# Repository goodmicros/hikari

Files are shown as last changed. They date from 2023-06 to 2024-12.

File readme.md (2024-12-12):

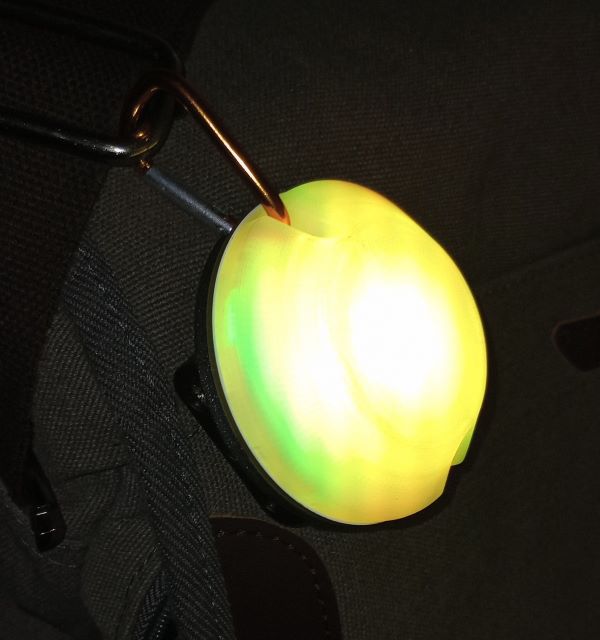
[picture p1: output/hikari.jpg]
badge


# Hikari
This is an all-in-one, battery powered, single RGBW led module designed to be used with the [WLED project](https://wled.me).
The goal is to provide inexpensive, portable lights for events and DIY use.

## Usage
Connect 3x AAA batteries and switch on. The USB port can be used to bypass the battery pack for extended usage.

If you want, you can further configure / adjust the light color and effects over WLAN with:
* WLED native phone app: [iOS App Store](https://apps.apple.com/us/app/wled-native/id6446207239) - [Google Play](https://play.google.com/store/apps/details?id=ca.cgagnier.wlednativeandroid)
* [LedFX](https://www.ledfx.app/) 
* [WLED compatibles](https://github.com/Aircoookie/WLED#-supported-light-control-interfaces)
* or by connecting to the device's IP address

### Modes  
* The switch turns the whole module on/off
* The button puts the device into sleep
* Two button presses sets the color to white (and disables the live mode)
    * back to normal with a long press
    * reboot the device to enable live mode again
* Hold the button for 6 seconds to reset WLAN config
* Hold the button for more than 12 seconds to factory reset WLED settings

## Wireless control / WLAN fallback
By default the device is looking for a Good Micros WLAN and tries to connect to it. 
If it can't find the WLAN it will create an access point which you can connect with your phone or laptop to change the effects and settings.  
The AP name is hikari- + the number of your device which is also printed on a sticker in the battery case. The default password for the AP is wled1234.

## Design requirements
* WLED compatible
* Battery powered with the possibility to bypass with USB power
* Brightness comparable to a strip of ws2812b leds
* Programmable without external hardware

## Troubleshooting
|issue|cause|solution|
|-----|-----|---|
|only green works| low battery| replace batteries or connect USB|
|stuck on red| USB connected while powered off| disconnect USB -> switch on -> connect USB|
|stuck on red| button pressed while powering on| power off -> power on without pressing button|

## Configuration (Advanced usage)
Install WLED via https://install.wled.me/  

The switch should be in the power-on position when programming.
If WLED installer doesn't allow you to erase the memory, hold the switch while connecting the power (the light should stay red).  

After successful flashing remove the device and plug it back in to refresh the serial port. After connecting you have the option to connect the device to WLAN. If it doesn't appear instantly press one of the options from WLED installer and click back to refresh the view.

pin configuration on WLED:
|color|pin|
|-----|---|
| red |16 |
|green|14 |
|blue |12 |
|white|13 |

[Case model](https://cad.onshape.com/documents/9da918a63413a7b839d4e473/w/a43791fa43f813add74c9832/e/dfbc73c4b037cd1ff73a47b7)

## Bugs
* ~CH340G VCC should be connected to 3.3V~

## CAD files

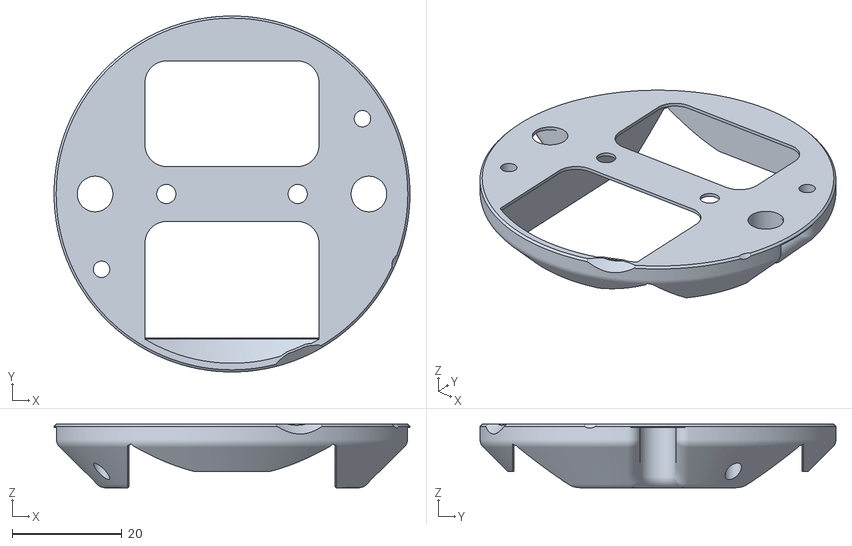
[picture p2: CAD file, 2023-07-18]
output/hikari_bottom_final.stl
65.0 x 65.0 x 11.6

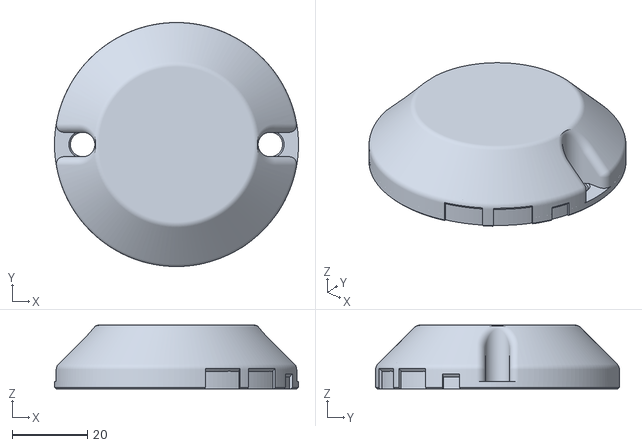
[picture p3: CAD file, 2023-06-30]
output/hikari_diffuser_final.stl
65.0 x 65.0 x 17.0

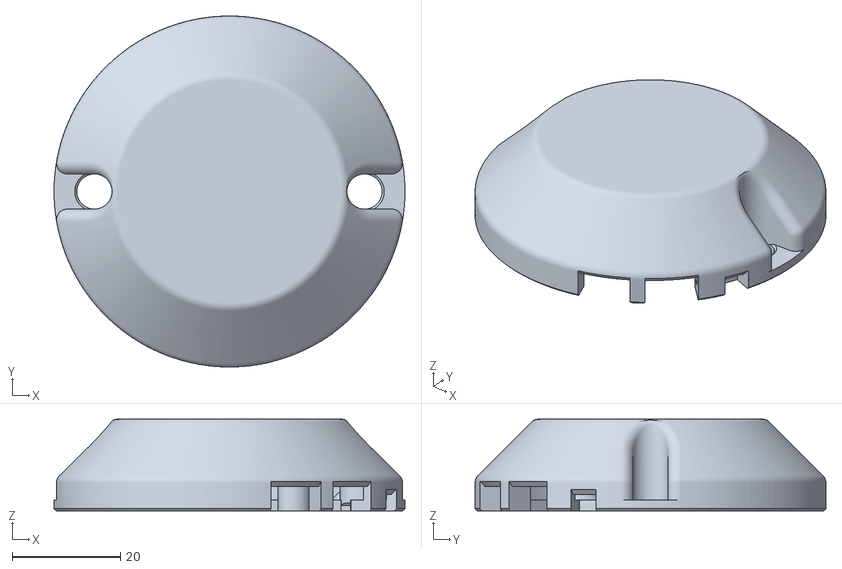
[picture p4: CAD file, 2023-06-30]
output/hikari_diffuser_final_no_supports.stl
65.0 x 65.0 x 17.0

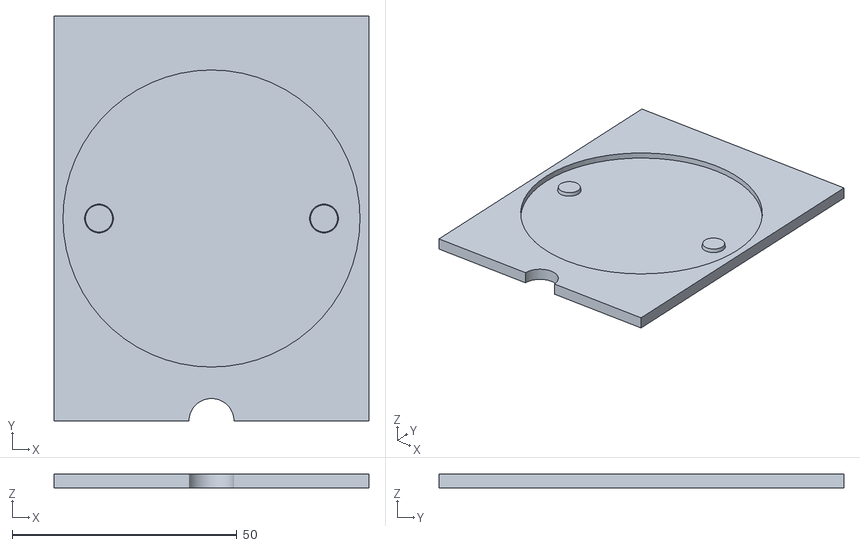
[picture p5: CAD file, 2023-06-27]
output/stencil-holder.stl
70.0 x 90.0 x 3.20

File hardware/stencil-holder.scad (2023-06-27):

$fn=60;
difference(){
    cube([70,90,2*1.6],center=true);
    cylinder(d=66, height = 1,6);
    translate([0,-45,0])
        cylinder(d=10,h=4, center=true);
}
for(a = [0,180]){
    rotate([0,0,a])
        translate([50/2,0,0])
            cylinder(d1=6.4, d2=6,  height = 1);
}

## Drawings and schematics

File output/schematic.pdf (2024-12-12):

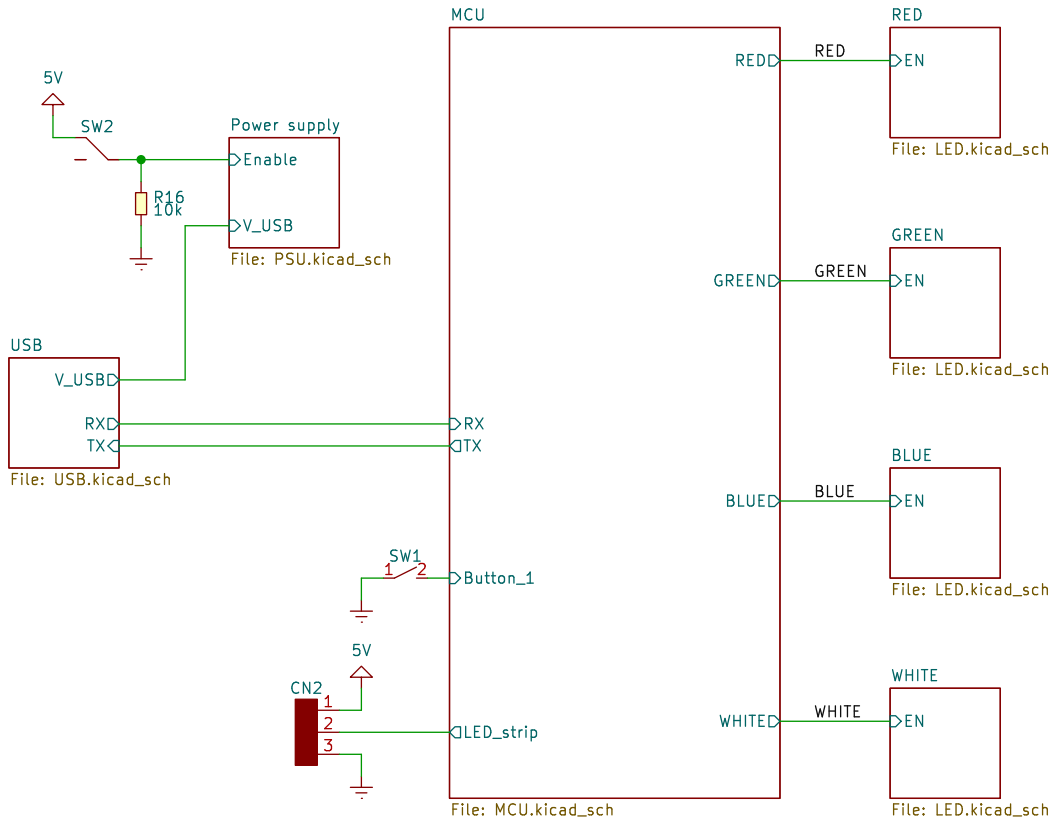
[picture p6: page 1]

File: LED.kicad_sch WHITE GREEN

Id: 1/8 Title: File: hikari.kicad_sch Sheet: /

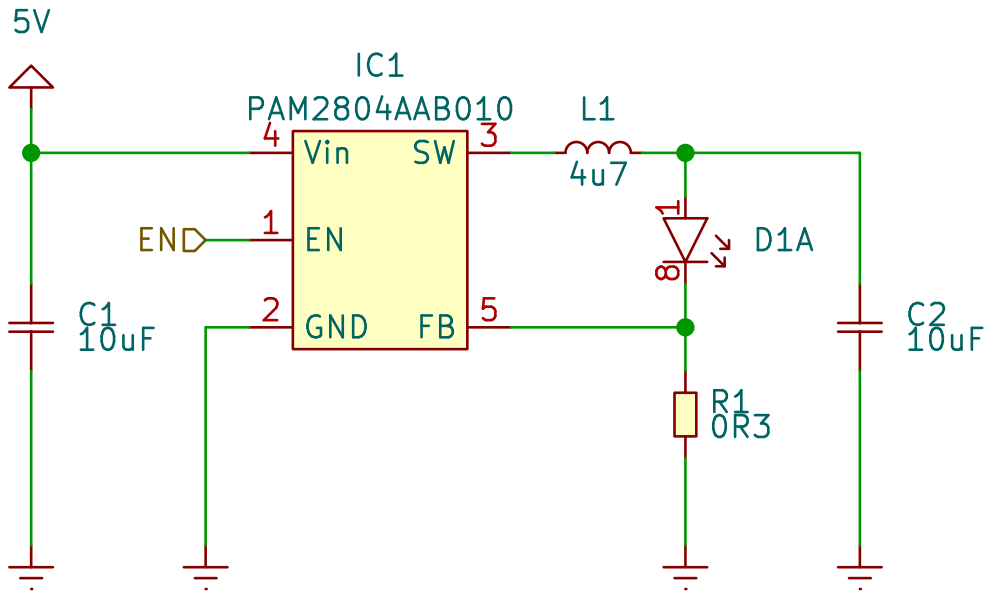
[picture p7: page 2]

Id: 2/8 Title: File: LED.kicad_sch Sheet: /RED/ C2

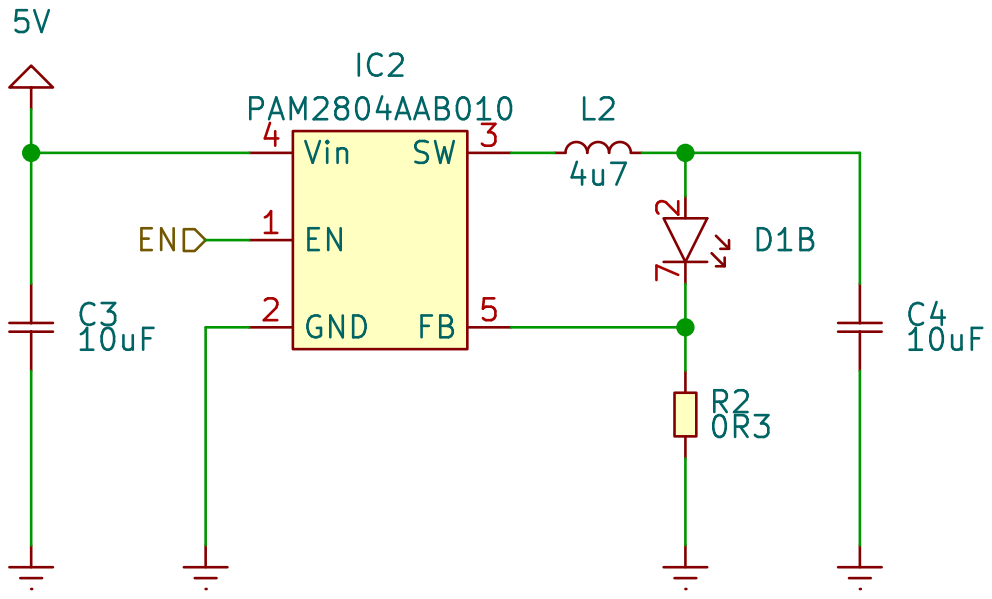
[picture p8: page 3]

Id: 3/8 Title: File: LED.kicad_sch Sheet: /GREEN/ C4

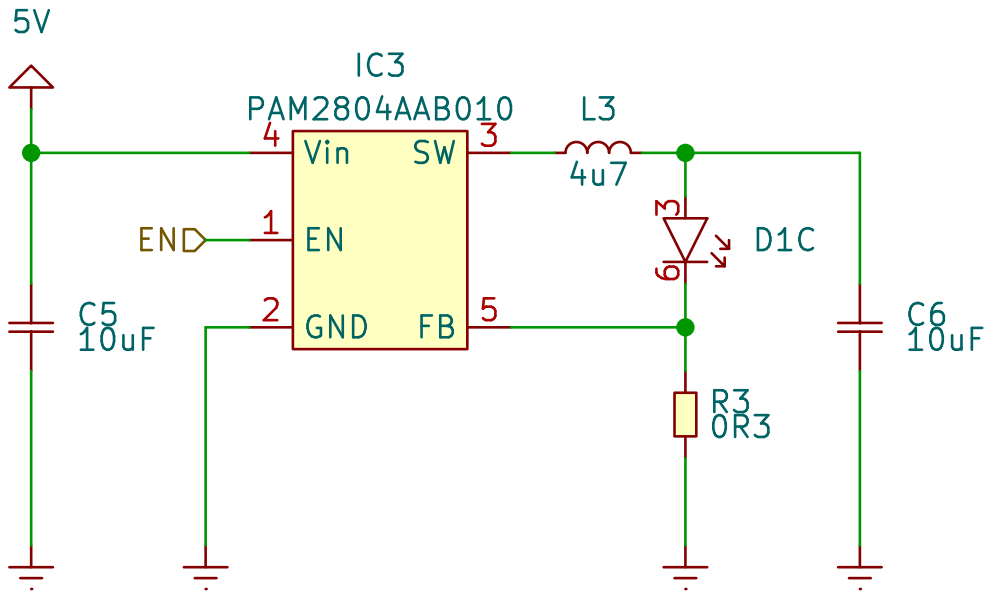
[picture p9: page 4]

Id: 4/8 Title: File: LED.kicad_sch Sheet: /BLUE/ C6

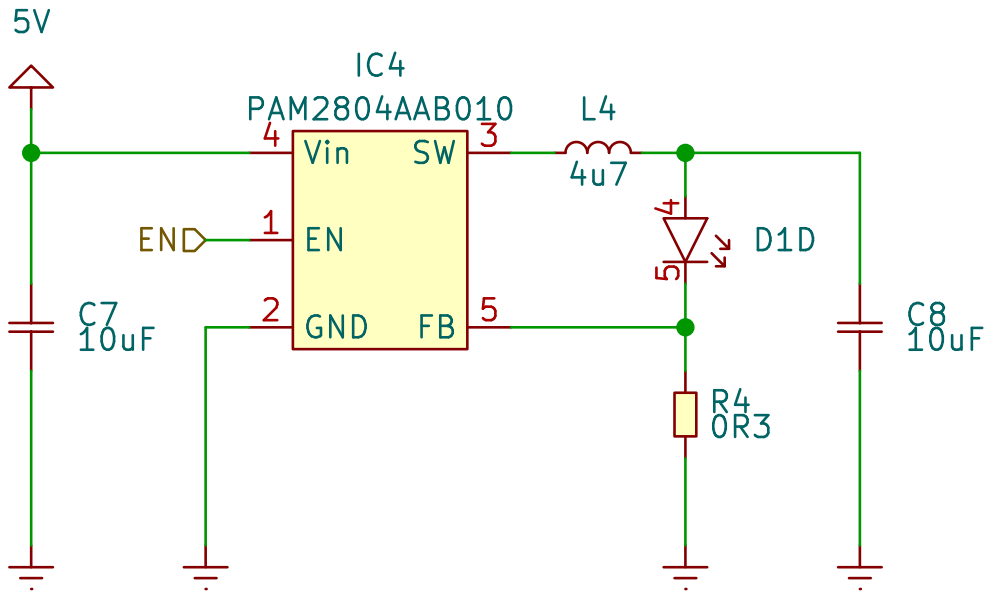
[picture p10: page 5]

Id: 5/8 Title: File: LED.kicad_sch Sheet: /WHITE/ C8

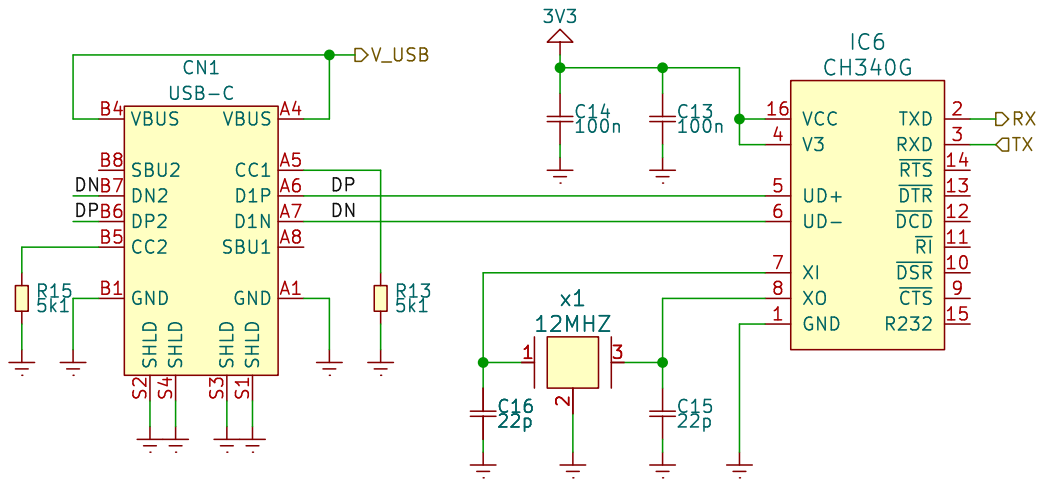
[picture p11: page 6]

Id: 6/8 Title: File: USB.kicad_sch Sheet: /USB/

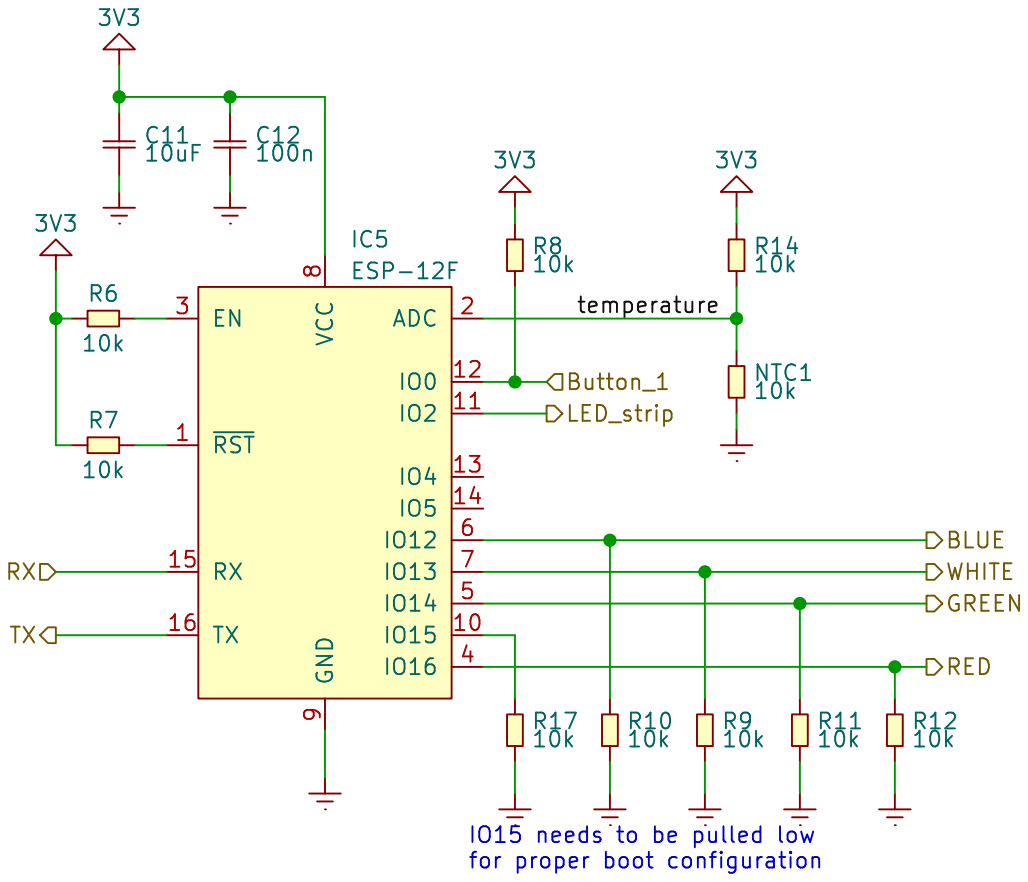
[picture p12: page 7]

Id: 7/8 Title: File: MCU.kicad_sch Sheet: /MCU/ R9

IO15 needs to be pulled low
for proper boot configuration

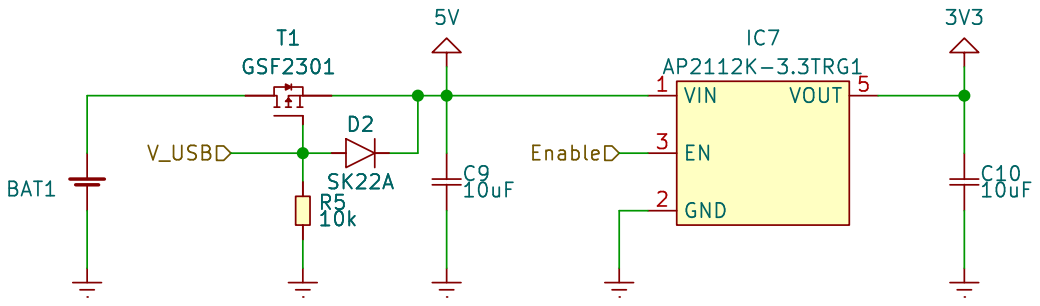
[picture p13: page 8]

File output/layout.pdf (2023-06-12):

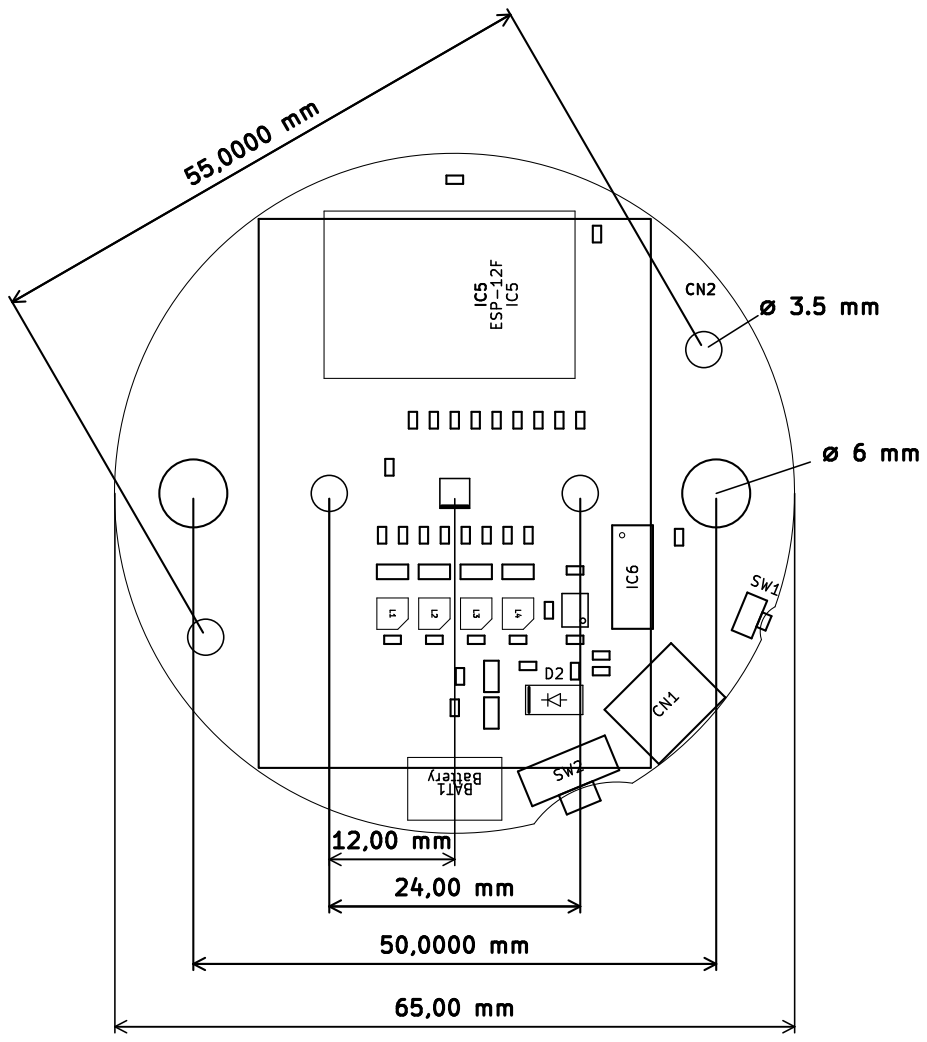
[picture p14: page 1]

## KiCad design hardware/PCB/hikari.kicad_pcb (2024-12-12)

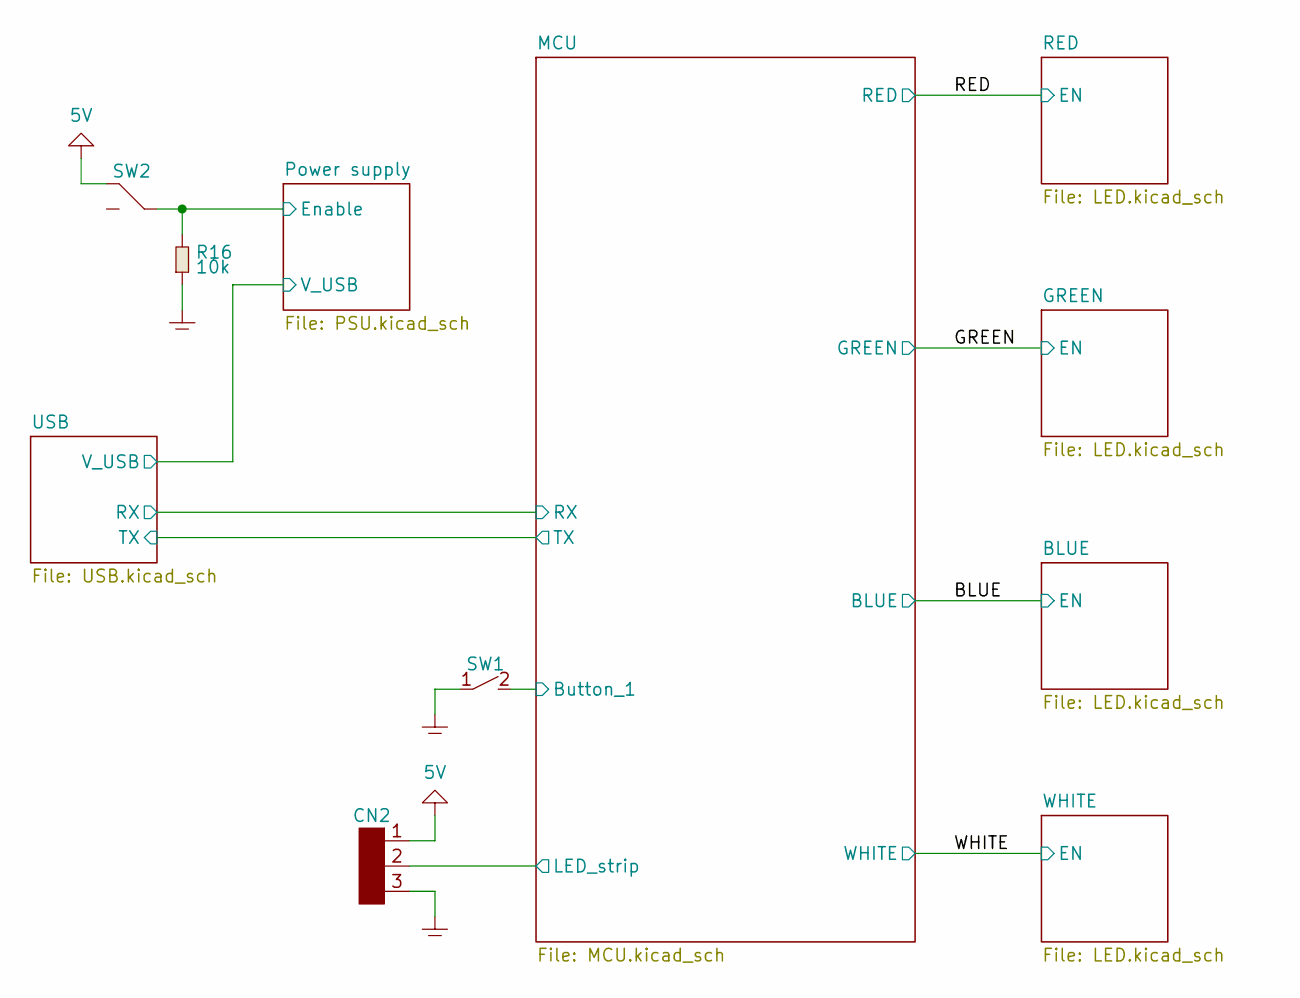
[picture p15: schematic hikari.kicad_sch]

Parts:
CN2: 1x3
R16: 10k; 0603; Digi-Key 13-RC0603JR-1010KLCT-ND
SW1: LS12W3-T; Digi-Key 1642-LS12W3-TCT-ND
SW2: JS102011SAQN; Digi-Key 401-1999-1-ND

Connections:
5V: CN2.1, SW2.1; also elsewhere on the board
/MCU/Button_1: SW1.2; also elsewhere on the board
/MCU/LED_strip: CN2.2; also elsewhere on the board
/Power supply/Enable: R16.2, SW2.2; also elsewhere on the board
GND: CN2.3, R16.1, SW1.0, SW1.1; also elsewhere on the board
unnamed: SW2.3, SW2.4

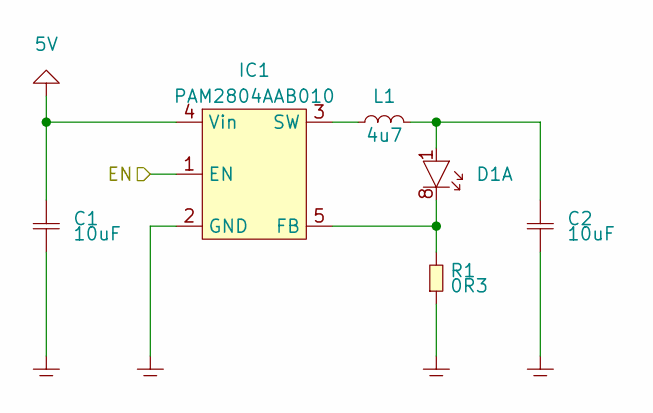
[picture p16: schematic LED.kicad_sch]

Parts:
C1, C2: 10uF; 0603; Digi-Key 1276-1119-1-ND
D1: QLSP06RGBXWAJ; 3030_8; MPN QLSP06RGBXWAJ; Digi-Key 3970-QLSP06RGBXWAJCT-ND
IC1: PAM2804AAB010; SOT-23-5; MPN PAM2804AAB010; Digi-Key PAM2804AAB010DICT-ND
L1: 4u7; CDRH2D11; Digi-Key 308-1590-1-ND
R1: 0R3; 0603; Digi-Key 273-KDV06FR300ETCT-ND

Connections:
5V: C1.1, IC1.4 (Vin); also elsewhere on the board
/RED: IC1.1 (EN); also elsewhere on the board
GND: C1.2, C2.2, IC1.2 (GND), R1.1; also elsewhere on the board
unnamed: C2.1, D1.1 (A), L1.2
unnamed: D1.8 (K), IC1.5 (FB), R1.2
unnamed 21: D1.2 (A); also elsewhere on the board
unnamed 22: D1.7 (K); also elsewhere on the board
unnamed 23: D1.3 (A); also elsewhere on the board
unnamed 24: D1.6 (K); also elsewhere on the board
unnamed 25: D1.4 (A); also elsewhere on the board
unnamed 26: D1.5 (K); also elsewhere on the board
unnamed: IC1.3 (SW), L1.1

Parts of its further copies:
C3, C4, C5, C6, C7, C8: 10uF; 0603; Digi-Key 1276-1119-1-ND
IC2, IC3, IC4: PAM2804AAB010; SOT-23-5; MPN PAM2804AAB010; Digi-Key PAM2804AAB010DICT-ND
L2, L3, L4: 4u7; CDRH2D11; Digi-Key 308-1590-1-ND
R2, R3, R4: 0R3; 0603; Digi-Key 273-KDV06FR300ETCT-ND

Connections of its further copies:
5V: C3.1, C5.1, C7.1, IC2.4 (Vin), IC3.4 (Vin), IC4.4 (Vin); also elsewhere on the board
/BLUE: IC3.1 (EN); also elsewhere on the board
/GREEN: IC2.1 (EN); also elsewhere on the board
/WHITE: IC4.1 (EN); also elsewhere on the board
GND: C3.2, C4.2, C5.2, C6.2, C7.2, C8.2, IC2.2 (GND), IC3.2 (GND), IC4.2 (GND), R2.1, R3.1, R4.1; also elsewhere on the board
unnamed 21: C4.1, L2.2; also elsewhere on the board
unnamed 22: IC2.5 (FB), R2.2; also elsewhere on the board
unnamed 23: C6.1, L3.2; also elsewhere on the board
unnamed 24: IC3.5 (FB), R3.2; also elsewhere on the board
unnamed 25: C8.1, L4.2; also elsewhere on the board
unnamed 26: IC4.5 (FB), R4.2; also elsewhere on the board
unnamed: IC2.3 (SW), L2.1
unnamed: IC3.3 (SW), L3.1
unnamed: IC4.3 (SW), L4.1

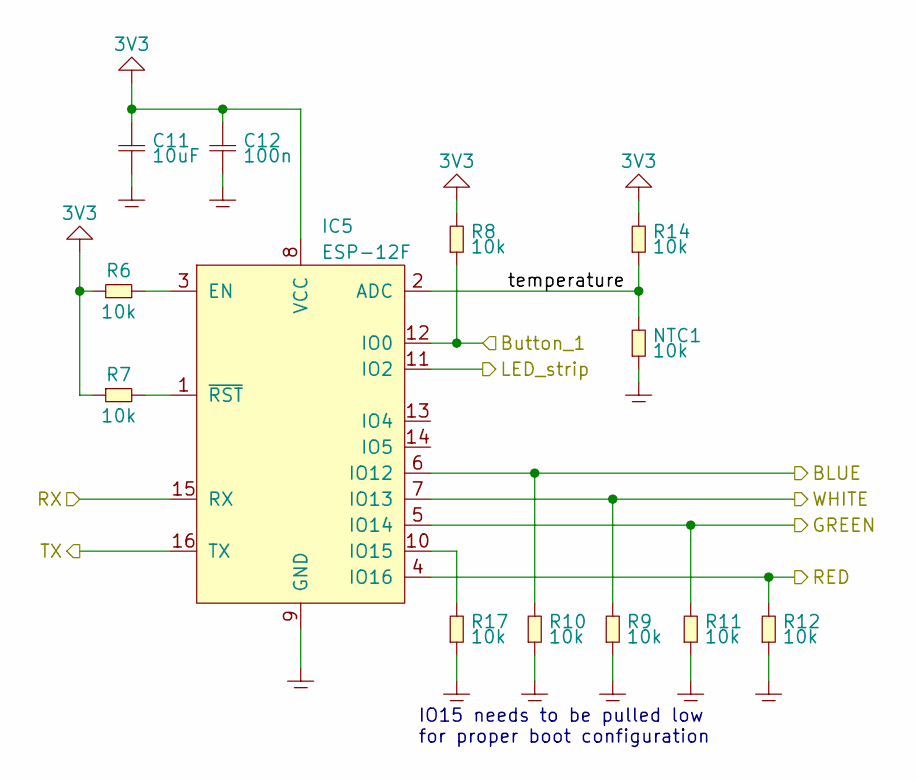
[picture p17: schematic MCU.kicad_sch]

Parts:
C11: 10uF; 0603; Digi-Key 1276-1119-1-ND
C12: 100n; 0603; Digi-Key 1276-1935-1-ND
IC5: ESP-12F
NTC1: 10k; 0603; Digi-Key 490-16279-1-ND
R6, R7, R8, R9, R10, R11, R12, R14, R17: 10k; 0603; Digi-Key 13-RC0603JR-1010KLCT-ND

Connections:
3V3: C11.1, C12.1, IC5.8 (VCC), R6.2, R7.1, R8.2, R14.2; also elsewhere on the board
/BLUE: IC5.6 (IO12), R10.2; also elsewhere on the board
/GREEN: IC5.5 (IO14), R11.2; also elsewhere on the board
/MCU/Button_1: IC5.12 (IO0), R8.1; also elsewhere on the board
/MCU/LED_strip: IC5.11 (IO2); also elsewhere on the board
/MCU/RX: IC5.15 (RX); also elsewhere on the board
/MCU/TX: IC5.16 (TX); also elsewhere on the board
/MCU/temperature: IC5.2 (ADC), NTC1.2, R14.1
/RED: IC5.4 (IO16), R12.2; also elsewhere on the board
/WHITE: IC5.7 (IO13), R9.2; also elsewhere on the board
GND: C11.2, C12.2, IC5.9 (GND), NTC1.1, R9.1, R10.1, R11.1, R12.1, R17.1; also elsewhere on the board
unnamed: IC5.3 (EN), R6.1
unnamed: IC5.10 (IO15), R17.2
unnamed: IC5.1 (~RST), R7.2

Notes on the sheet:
IO15 needs to be pulled low for proper boot configuration

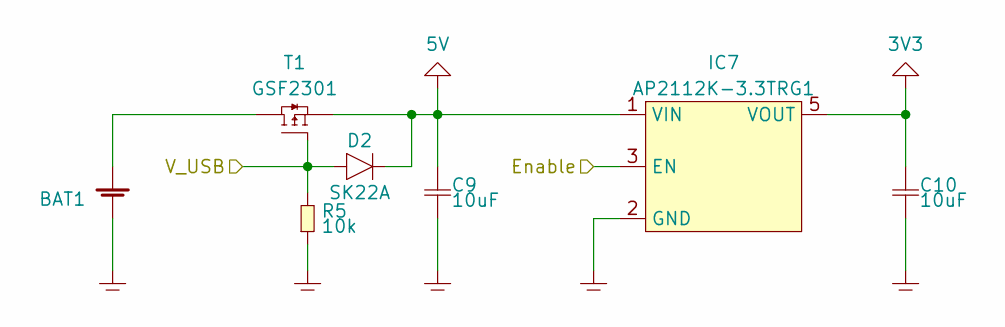
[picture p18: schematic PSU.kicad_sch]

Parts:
BAT1: Battery; Battery_solder-points
C9, C10: 10uF; 0603; Digi-Key 1276-1119-1-ND
D2: SK22A; DO-214AC; Digi-Key 4786-SK22ACT-ND
IC7: AP2112K-3.3TRG1; SOT-23-5; MPN AP2112K-3.3TRG1; Digi-Key AP2112K-3.3TRG1DICT-ND
R5: 10k; 0603; Digi-Key 13-RC0603JR-1010KLCT-ND
T1: GSF2301; SOT-23; Digi-Key 4786-GSF2301CT-ND

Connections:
3V3: C10.1, IC7.5 (VOUT); also elsewhere on the board
5V: C9.1, D2.2 (K), IC7.1 (VIN), T1.2 (S); also elsewhere on the board
/Power supply/Enable: IC7.3 (EN); also elsewhere on the board
/Power supply/V_USB: D2.1 (A), R5.2, T1.1 (G); also elsewhere on the board
GND: BAT1.2 (-), C9.2, C10.2, IC7.2 (GND), R5.1; also elsewhere on the board
unnamed: BAT1.1 (+), T1.3 (D)

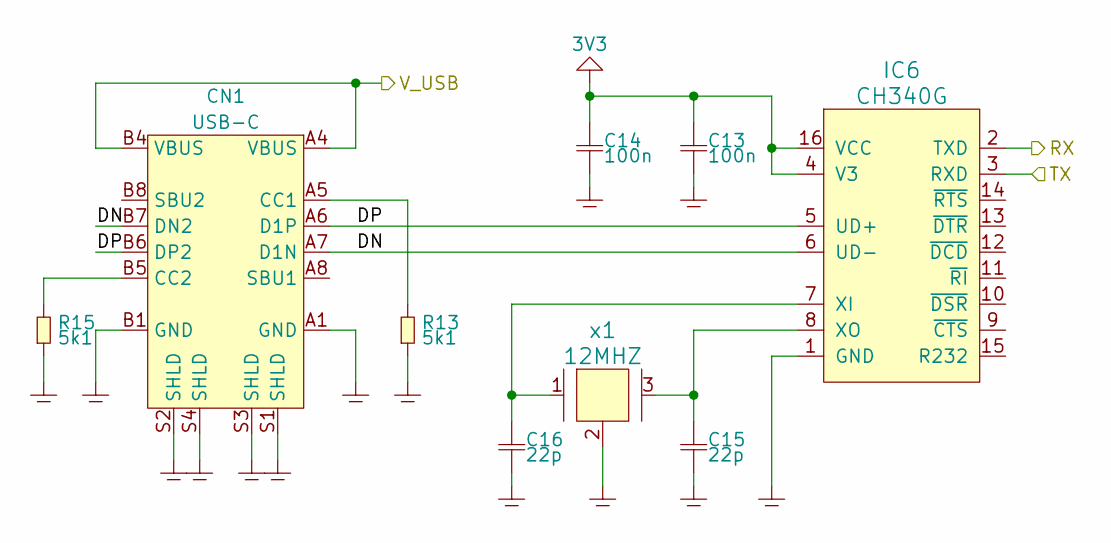
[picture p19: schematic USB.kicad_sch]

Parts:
C13, C14: 100n; 0603; Digi-Key 1276-1935-1-ND
C15, C16: 22p; 0603; Digi-Key 1292-1503-1-ND
CN1: USB-C; USB4105-GF-A; MPN USB4105-GF-A; Digi-Key 2073-USB4105-GF-ACT-ND
IC6: CH340G; SOP-16
R13, R15: 5k1; 0603; Digi-Key 13-RC0603FR-135K1LCT-ND
x1: 12MHZ; 3.2x2.5CXO; Digi-Key 2151-RH100-12.000-18-2020-EXT-TRCT-ND

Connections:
3V3: C13.1, C14.1, IC6.4 (V3), IC6.16 (VCC); also elsewhere on the board
/MCU/RX: IC6.2 (TXD); also elsewhere on the board
/MCU/TX: IC6.3 (RXD); also elsewhere on the board
/Power supply/V_USB: CN1.A4 (VBUS), CN1.B4 (VBUS); also elsewhere on the board
/USB/DN: CN1.A7 (D1N), CN1.B7 (DN2), IC6.6 (UD-)
/USB/DP: CN1.A6 (D1P), CN1.B6 (DP2), IC6.5 (UD+)
GND: C13.2, C14.2, C15.2, C16.2, CN1.A1 (GND), CN1.B1 (GND), CN1.S1 (SHLD), CN1.S2 (SHLD), CN1.S3 (SHLD), CN1.S4 (SHLD), IC6.1 (GND), R13.1, R15.1, x1.2, x1.4; also elsewhere on the board
unnamed: CN1.A5 (CC1), R13.2
unnamed: CN1.B5 (CC2), R15.2
unnamed: C16.1, IC6.7 (XI), x1.1
unnamed: C15.1, IC6.8 (XO), x1.3

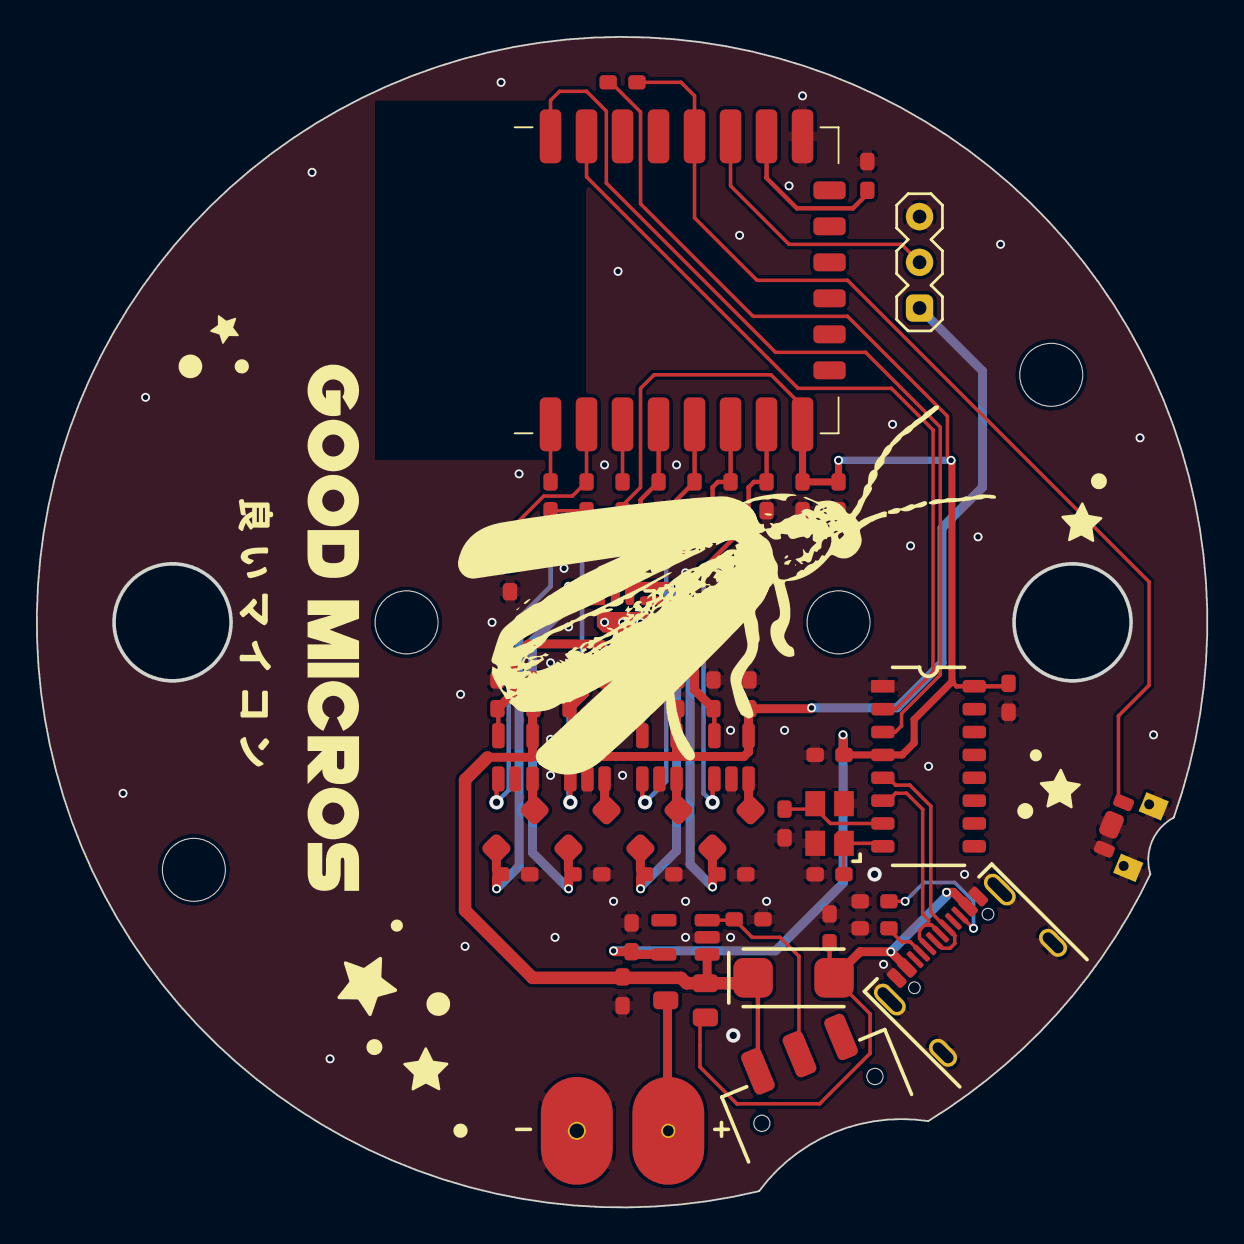
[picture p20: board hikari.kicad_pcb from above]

Board: 2 copper layers, 65.0 x 65.0 mm, 54 parts (0 on the bottom side), 36 nets.

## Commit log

2023-04-27 created schematic hierarchy
    [LED.kicad_sch, MCU.kicad_sch, PSU.kicad_sch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]
2023-05-10 added usb serial and mcu
    [MCU.kicad_sch, PSU.kicad_sch, USB.kicad_sch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]
2023-05-17 cleaned up layout, added 3V3 regulator, changed NTC to connect to gnd instead of 3V3, added README
    [MCU.kicad_sch, PSU.kicad_sch, USB.kicad_sch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]
2023-05-19 added esp12 footprint
    [MCU.kicad_sch, hikari.kicad_sch]
2023-05-23 fixed power symbols from showing up in BOM
    [LED.kicad_sch, MCU.kicad_sch, PSU.kicad_sch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]
2023-05-23 started layout, updated readme, annotated power symbols...
    [LED.kicad_sch, MCU.kicad_sch, PSU.kicad_sch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]
2023-05-29 worked layout, fixed 3V3 being GND net
    [MCU.kicad_sch, PSU.kicad_sch, USB.kicad_sch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]
2023-05-30 added type-c connector
    [USB.kicad_sch, hikari.kicad_pcb, hikari.kicad_sch]
2023-06-05 did most of todo items
    [MCU.kicad_sch, PSU.kicad_sch, USB.kicad_sch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]
2023-06-06 rough layout done
    [hikari.kicad_pcb]
2023-06-06 all signals routed
    [hikari.kicad_pcb]
2023-06-06 added graphics on top silk
    [hikari.kicad_pcb]
2023-06-07 added gaps on pcb under switches
    [hikari.kicad_pcb]
2023-06-07 added clearance from copper pour to pcb edge, increased soldermask openings, DRC ok
    [hikari.kicad_pcb]
2023-06-07 added Digi-Key part numbers to BOM
    [LED.kicad_sch, MCU.kicad_sch, PSU.kicad_sch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]
2023-06-08 reviewn completed, fixes required
    [MCU.kicad_sch, hikari.kicad_sch]
2023-06-12 fixed errors, ready for order
    [MCU.kicad_sch, hikari.kicad_pcb, hikari.kicad_sch]
2023-06-13 added step, preview. fixed hole diameter being documented 6 mm
    [hikari.kicad_pcb]
2023-06-27 added pcb hoder for stencil work
    [stencil-holder.scad, stencil-holder.stl]
2023-06-30 Added hikari case stl files
    [hikari_bottom_final.stl, hikari_diffuser_final.stl, hikari_diffuser_final_no_supports.stl]
2023-07-18 Tiny support added
    [hikari_bottom_final.stl]
2023-08-07 Update readme.md
    added button information and installing stuff
2023-08-15 moved pcb and scad files under hardware
    [LED.kicad_sch, MCU.kicad_sch, PSU.kicad_sch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]
2024-12-12 fixed the pcb being powered via ch340g
    [LED.kicad_sch, MCU.kicad_sch, PSU.kicad_sch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]
